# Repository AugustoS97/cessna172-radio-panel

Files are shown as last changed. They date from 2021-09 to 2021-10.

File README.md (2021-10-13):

# cessna-radio-panel

Radio panel for COM or NAV for a Cessna 172 to use with MSFS2020, XPlane and Prepar3D using the software MobiFlight.

# Repo contents

## Cessna-radio-stack-pcb
This folder contents the PCB design for the radio module. The design is the same for COM and NAV, it only changes on the frame. This PCB needs to be connected to the Arduino Mega using the Mega-pro-mini module designed in this repository. There is a GERBER folder to send the design to JLCPCB (www.jlcpcb.com) or you can ask me to buy it finished (augustosamuelhdezmartin@gmail.com).

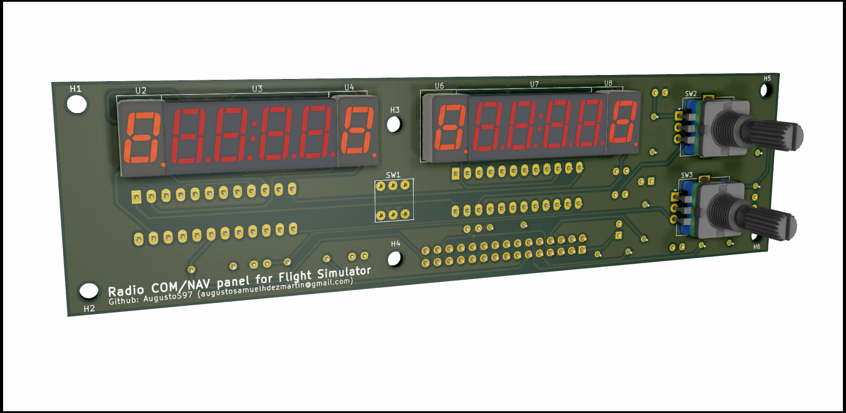
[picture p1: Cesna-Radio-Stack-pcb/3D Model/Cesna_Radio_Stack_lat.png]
Render PCB radio

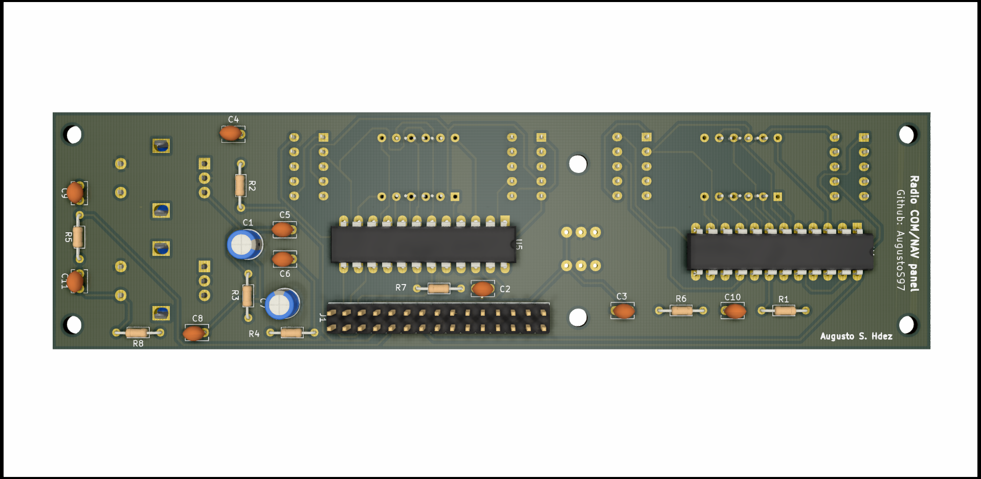
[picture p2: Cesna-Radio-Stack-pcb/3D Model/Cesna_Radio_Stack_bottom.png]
Render PCB bottom


To make this PCB you need this components (you can find the list in cessna172-radio-panel/Cesna-Radio-Stack-pcb/Docs/Cesna_Radio_Stack.csv):
- 4x Display 7 segments 0.36" 1 bit Common Cathode red (https://www.aliexpress.com/item/1005001852229452.html?spm=a2g0o.cart.0.0.44e13c00yVY6Ir&mp=1)
- 2x Display 7 segments 0.36" 4 bit Common Cathode red AS3161 (https://www.aliexpress.com/item/32673704841.html?spm=a2g0o.cart.0.0.44e13c00yVY6Ir&mp=1).
- 2x Rottary Encoder EC11 (https://es.aliexpress.com/item/1005002931777351.html?spm=a2g0o.cart.0.0.44e13c00yVY6Ir&mp=1) 
- 1x Button 8x8 (https://www.aliexpress.com/item/32467872702.html?spm=a2g0o.cart.0.0.44e13c00yVY6Ir&mp=1)
- 2x MAX7219 DIP24 (https://www.aliexpress.com/item/32874536319.html?spm=a2g0o.cart.0.0.44e13c00yVY6Ir&mp=1)
- 1x PinHeader 2x36 pins (https://www.aliexpress.com/item/33004522737.html?spm=a2g0o.cart.0.0.44e13c00yVY6Ir&mp=1)
- 8x 1k Resistor THT
- 7x 10nF Ceramic Capacitor THT
- 2x 150nF Ceramic Capacitor THT
- 2x 22uF Electrolitic Capcitor 16V

## Mega2560-pro-mini-radio
This folder contents the PCB design for the microcontroller. The design connects 2 NAV modules, 2 COM modules or 1 NAv and 1 COM modules. There is a GERBER folder to send the design to JLCPCB (www.jlcpcb.com) or you can ask me to buy it finished (augustosamuelhdezmartin@gmail.com).

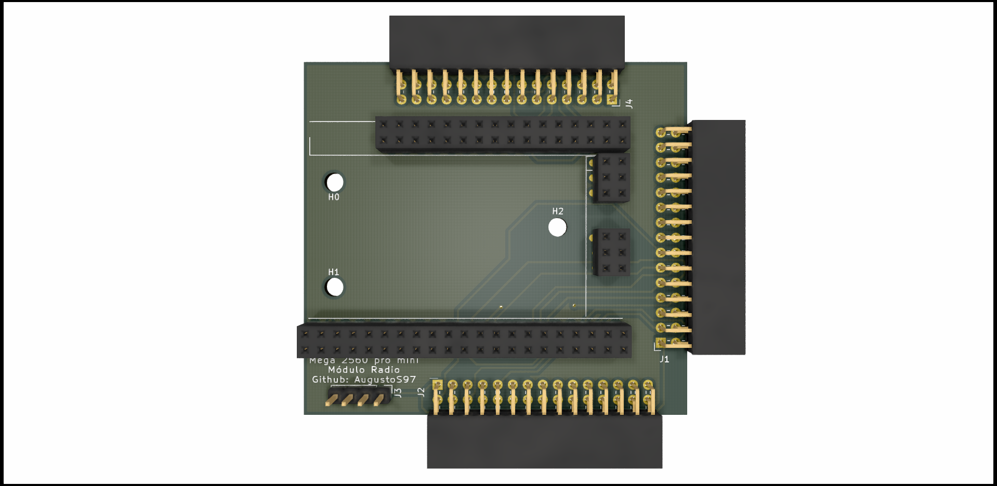
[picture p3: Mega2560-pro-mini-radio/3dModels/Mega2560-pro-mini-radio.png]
Render PCB radio


To make this PCB you need this components (you can find the list in cessna172-radio-panel/Mega2560-pro-mini-radio/docs/Mega2560-pro-mini-radio.csv):
- 1x Mega 2650 Pro mini (https://www.aliexpress.com/item/1005001798708448.html?spm=a2g0o.cart.0.0.44e13c00yVY6Ir&mp=1)
- 3x PinHeader male 2x36 pins 2.54 mm (https://www.aliexpress.com/item/32993182990.html?spm=a2g0o.cart.0.0.44e13c00yVY6Ir&mp=1)
- 3x PinHeader Female 1x40 pins 2.54mm (https://www.aliexpress.com/item/32993182990.html?spm=a2g0o.cart.0.0.44e13c00yVY6Ir&mp=1)
- 2x IDC 2x20 pins 2.54mm Cable (https://www.aliexpress.com/item/33029492417.html?spm=a2g0o.cart.0.0.44e13c00yVY6Ir&mp=1): One for each module

## Frame Design
This folders contents the FreeCAD design for the exterior panel. It is based on the c172-xpndr design (https://github.com/kkr0kk/c172-xpndr), so it must be use with this Transponder and AutoPilot modules.

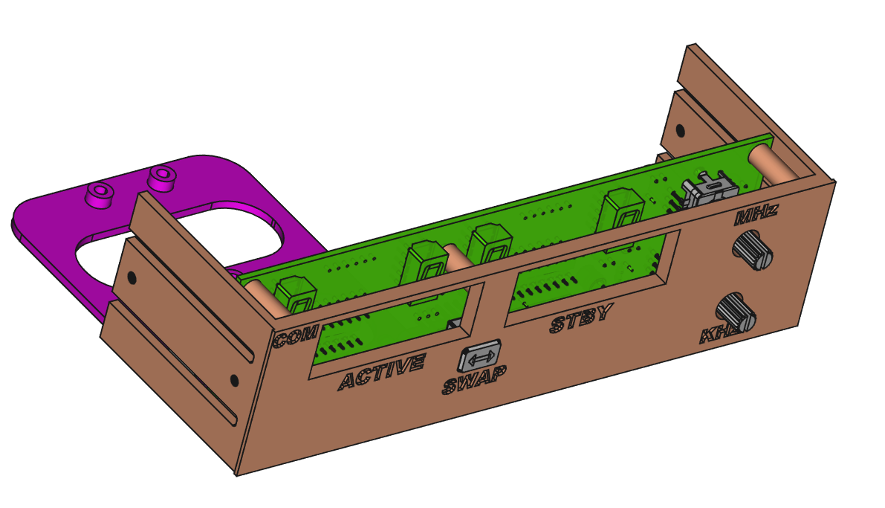
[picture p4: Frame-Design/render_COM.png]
FreeCAD design


Also the 3D model are available in STL folder, so you can print this panels with 2 colors or you can also contact me to buy a finished panel (augustosamuelhdezmartin@gmail.com).

## Assembly 
Finallly, the COM panel is assembly as shown in the next picture.

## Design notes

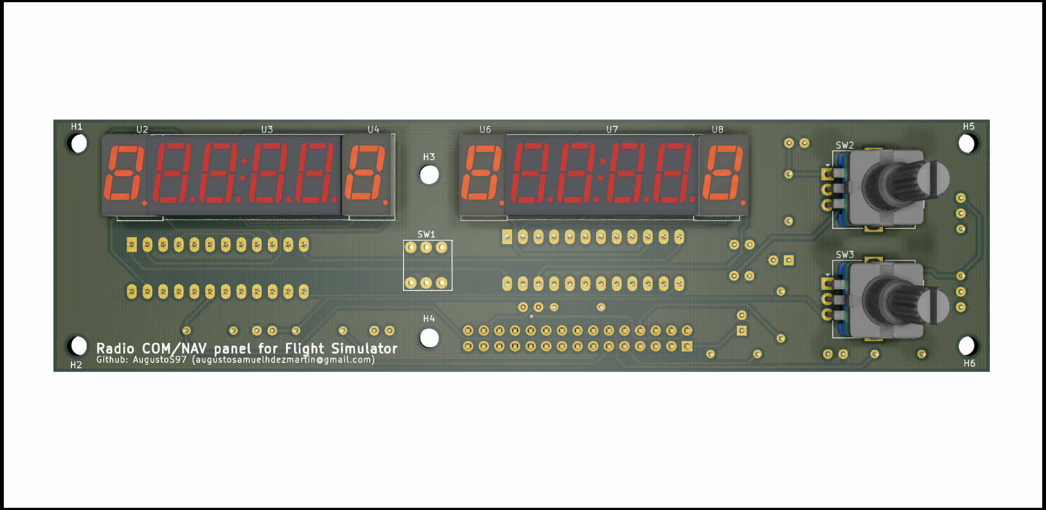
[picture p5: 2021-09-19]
Cesna-Radio-Stack-pcb/3D Model/Cesna_Radio_Stack.png

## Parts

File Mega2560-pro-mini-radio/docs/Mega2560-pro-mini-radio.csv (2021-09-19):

Ref | Qnty | Value | Cmp name | Footprint | Description | Vendor
J1, | 1 | COM_CONN | Conn_02x15_Odd_Even | Connector_PinSocket_2.54mm:PinSocket_2x15_P2.54mm_Horizontal | Generic connector, double row, 02x15, odd/even pin numbering scheme (row 1 odd numbers, row 2 even numbers), script generated (kicad-library-utils/schlib/autogen/connector/)
J2, | 1 | NAV_CONN | Conn_02x15_Odd_Even | Connector_PinSocket_2.54mm:PinSocket_2x15_P2.54mm_Horizontal | Generic connector, double row, 02x15, odd/even pin numbering scheme (row 1 odd numbers, row 2 even numbers), script generated (kicad-library-utils/schlib/autogen/connector/)
J3, | 1 | Power_Conn | Conn_01x04 | Connector_PinHeader_2.54mm:PinHeader_1x04_P2.54mm_Vertical | Generic connector, single row, 01x04, script generated (kicad-library-utils/schlib/autogen/connector/)
MCU1, | 1 | Mega_Embebido | Master_Arduino_Mega_Embebido_Arduino_Mega_v3 | Mega2560-pro-mini-radio:MEGA_Embebido

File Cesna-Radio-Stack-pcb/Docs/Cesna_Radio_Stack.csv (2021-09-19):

Ref | Qnty | Value | Cmp name | Footprint | Description | Vendor
C1, C7, | 2 | 22uF | CP_Small | Capacitor_THT:CP_Radial_D5.0mm_P2.50mm | Polarized capacitor, small symbol
C2, C8, | 2 | 150nF | C_Small | Capacitor_THT:C_Disc_D3.8mm_W2.6mm_P2.50mm | Unpolarized capacitor, small symbol
C3, C4, C5, C6, C9, C10, C11, | 7 | 10nF | C_Small | Capacitor_THT:C_Disc_D3.8mm_W2.6mm_P2.50mm | Unpolarized capacitor, small symbol
J1, | 1 | Conn_02x15_Odd_Even | Conn_02x15_Odd_Even | Connector_PinHeader_2.54mm:PinHeader_2x15_P2.54mm_Vertical | Generic connector, double row, 02x15, odd/even pin numbering scheme (row 1 odd numbers, row 2 even numbers), script generated (kicad-library-utils/schlib/autogen/connector/)
R1, R2, R3, R4, R5, R6, R7, R8, | 8 | 10k | R_Small | Resistor_THT:R_Axial_DIN0204_L3.6mm_D1.6mm_P7.62mm_Horizontal | Resistor, small symbol
SW1, | 1 | SW_COM-DPDT 8x8 mm | SW_Push_DPDT | Button_Switch_THT:SW_DIP_SPSTx03_Slide_9.78x9.8mm_W7.62mm_P2.54mm | Momentary Switch, dual pole double throw
SW2, | 1 | NAV_ENC-EC11 | Rotary_Encoder_Switch | Rotary_Encoder:RotaryEncoder_Alps_EC12E-Switch_Vertical_H20mm | Rotary encoder, dual channel, incremental quadrate outputs, with switch
SW3, | 1 | COM_ENC-EC11 | Rotary_Encoder_Switch | Rotary_Encoder:RotaryEncoder_Alps_EC12E-Switch_Vertical_H20mm | Rotary encoder, dual channel, incremental quadrate outputs, with switch
U1, U5, | 2 | MAX7219 | MAX7219 | Package_DIP:DIP-24_W7.62mm_LongPads | 8-Digit LED Display Driver
U2, | 1 | LD-3161-AS NAV/COM_ACTV | HDSP-A153 | Cesna_Radio_Stack:3161AS_7_Segmentos | One digit 7 segment red, common cathode
U3, | 1 | 3641-AS NAV/COM_ACTV | CC56-12EWA | Cesna_Radio_Stack:3641-AS | 4 digit 7 segment high efficiency red LED, common cathode
U4, | 1 | LD-3161-AS NAV/COM_ACTV_KHZ | HDSP-A153 | Cesna_Radio_Stack:3161AS_7_Segmentos | One digit 7 segment red, common cathode
U6, | 1 | LD-3161-AS NAV/COM_STB | HDSP-A153 | Cesna_Radio_Stack:3161AS_7_Segmentos | One digit 7 segment red, common cathode
U7, | 1 | 3641-AS NAV/COM_STB | CC56-12EWA | Cesna_Radio_Stack:3641-AS | 4 digit 7 segment high efficiency red LED, common cathode
U8, | 1 | LD-3161-AS NAV/COM_STB_KHZ | HDSP-A153 | Cesna_Radio_Stack:3161AS_7_Segmentos | One digit 7 segment red, common cathode

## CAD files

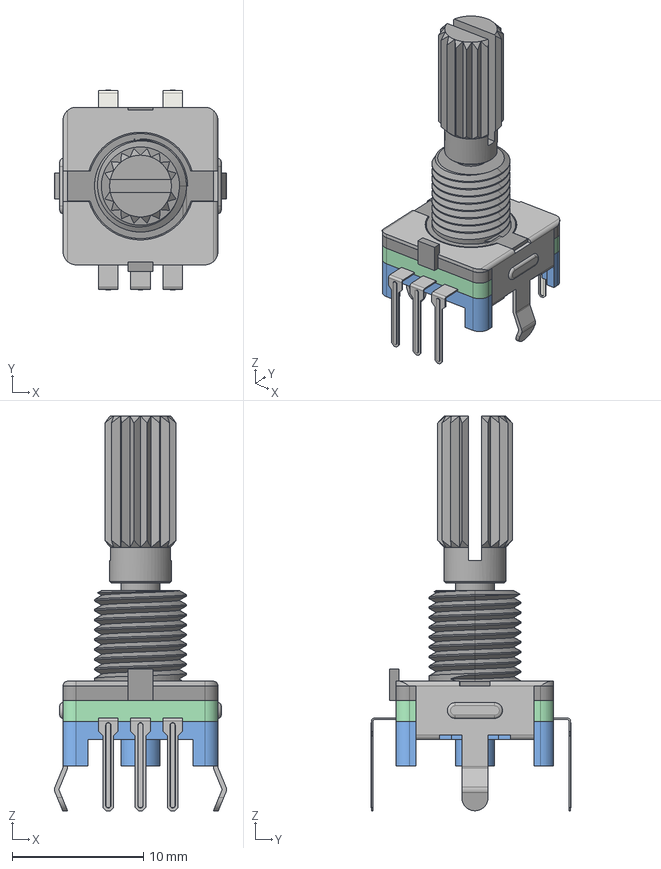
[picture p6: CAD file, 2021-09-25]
Frame-Design/EC11_Rotary_Encoder_Switched.step
13.1 x 15.3 x 30.1 mm

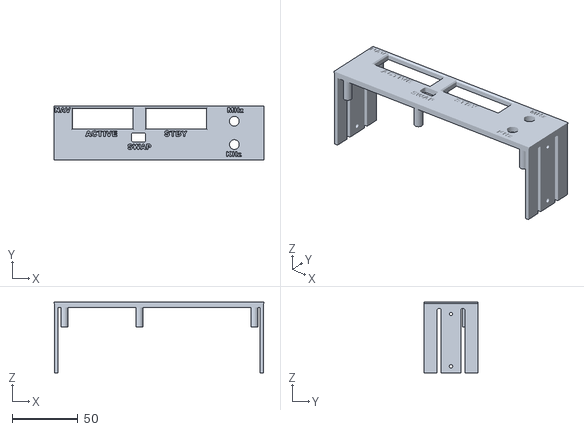
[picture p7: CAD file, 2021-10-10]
STL/Frame-NAV.stl
160.0 x 41.0 x 54.0

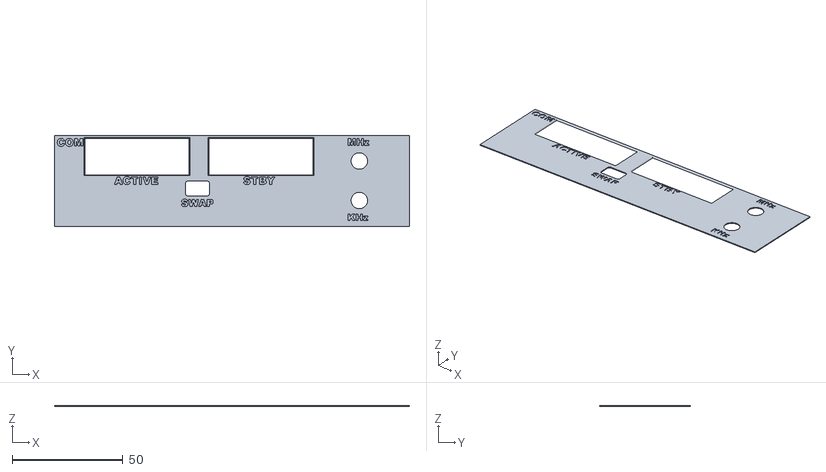
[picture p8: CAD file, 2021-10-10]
STL/Frame-COM-front.stl
160.0 x 41.0 x 0.4

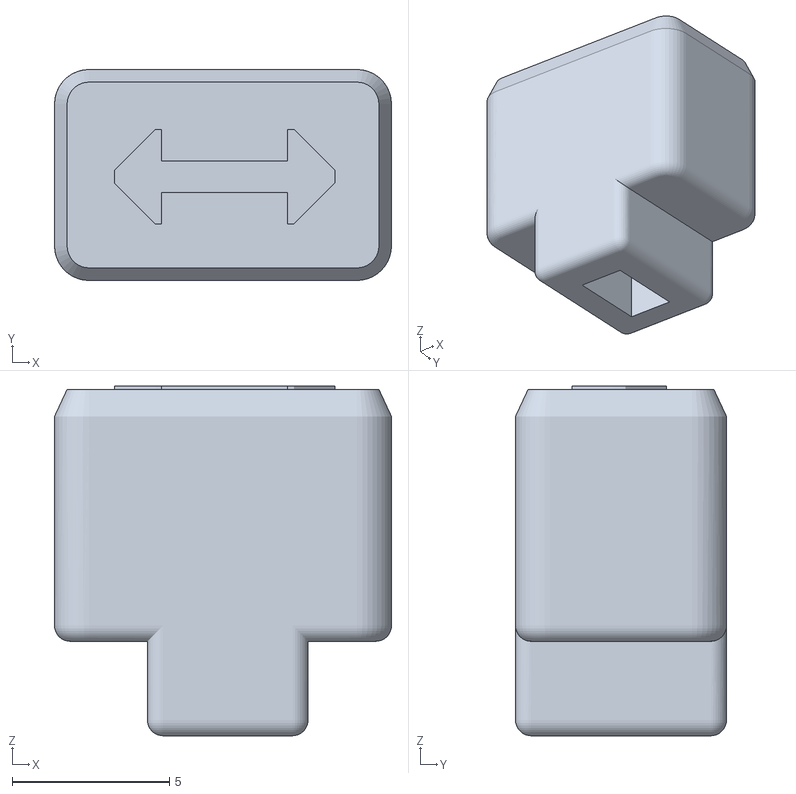
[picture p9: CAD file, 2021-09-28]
STL/Swap-Button.stl
10.7 x 6.70 x 11.1

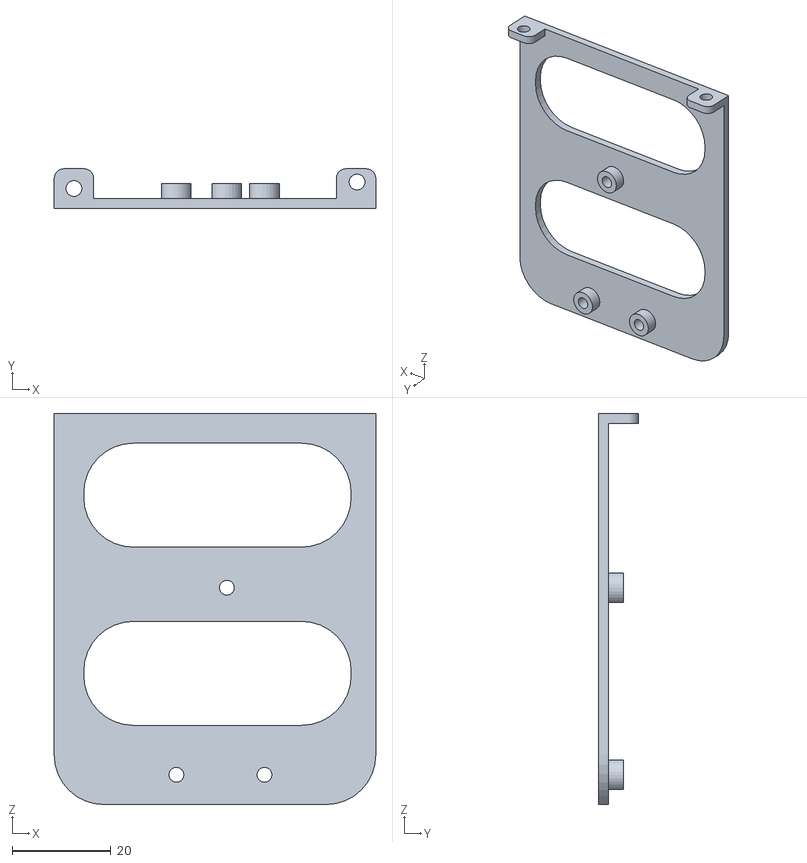
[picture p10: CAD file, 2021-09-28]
STL/Soporte-ATMega.stl
65.0 x 8.00 x 79.0

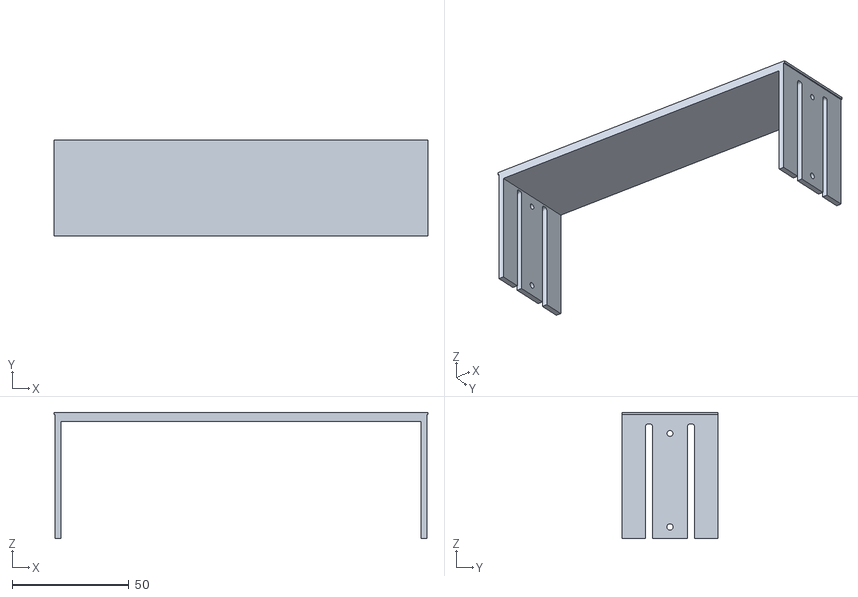
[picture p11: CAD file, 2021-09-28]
STL/Marco-vacio.stl
160.0 x 41.0 x 54.0

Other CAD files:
Frame-Design/chassis_without_text.STL
STL/Frame-COM.stl
STL/Button.stl

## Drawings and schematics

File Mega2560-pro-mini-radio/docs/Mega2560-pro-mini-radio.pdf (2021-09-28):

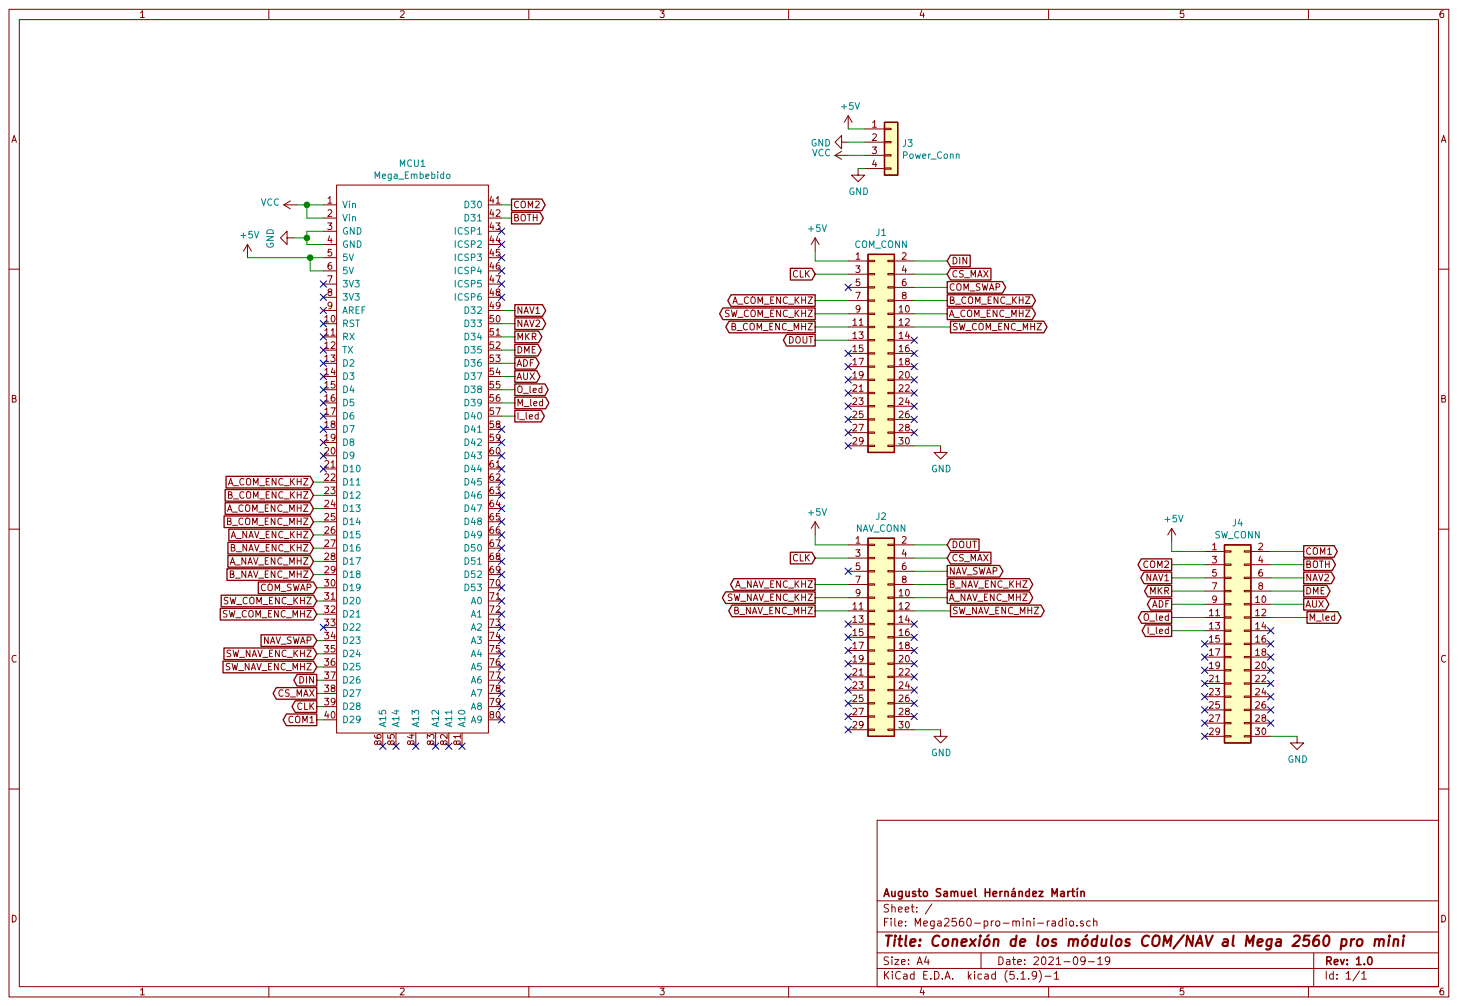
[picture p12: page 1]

File: Mega2560-pro-mini-radio.sch Sheet: / Augusto Samuel Hernández Martín GND

Id: 1/1 Title: Conexión de los módulos COM/NAV al Mega 2560 pro mini

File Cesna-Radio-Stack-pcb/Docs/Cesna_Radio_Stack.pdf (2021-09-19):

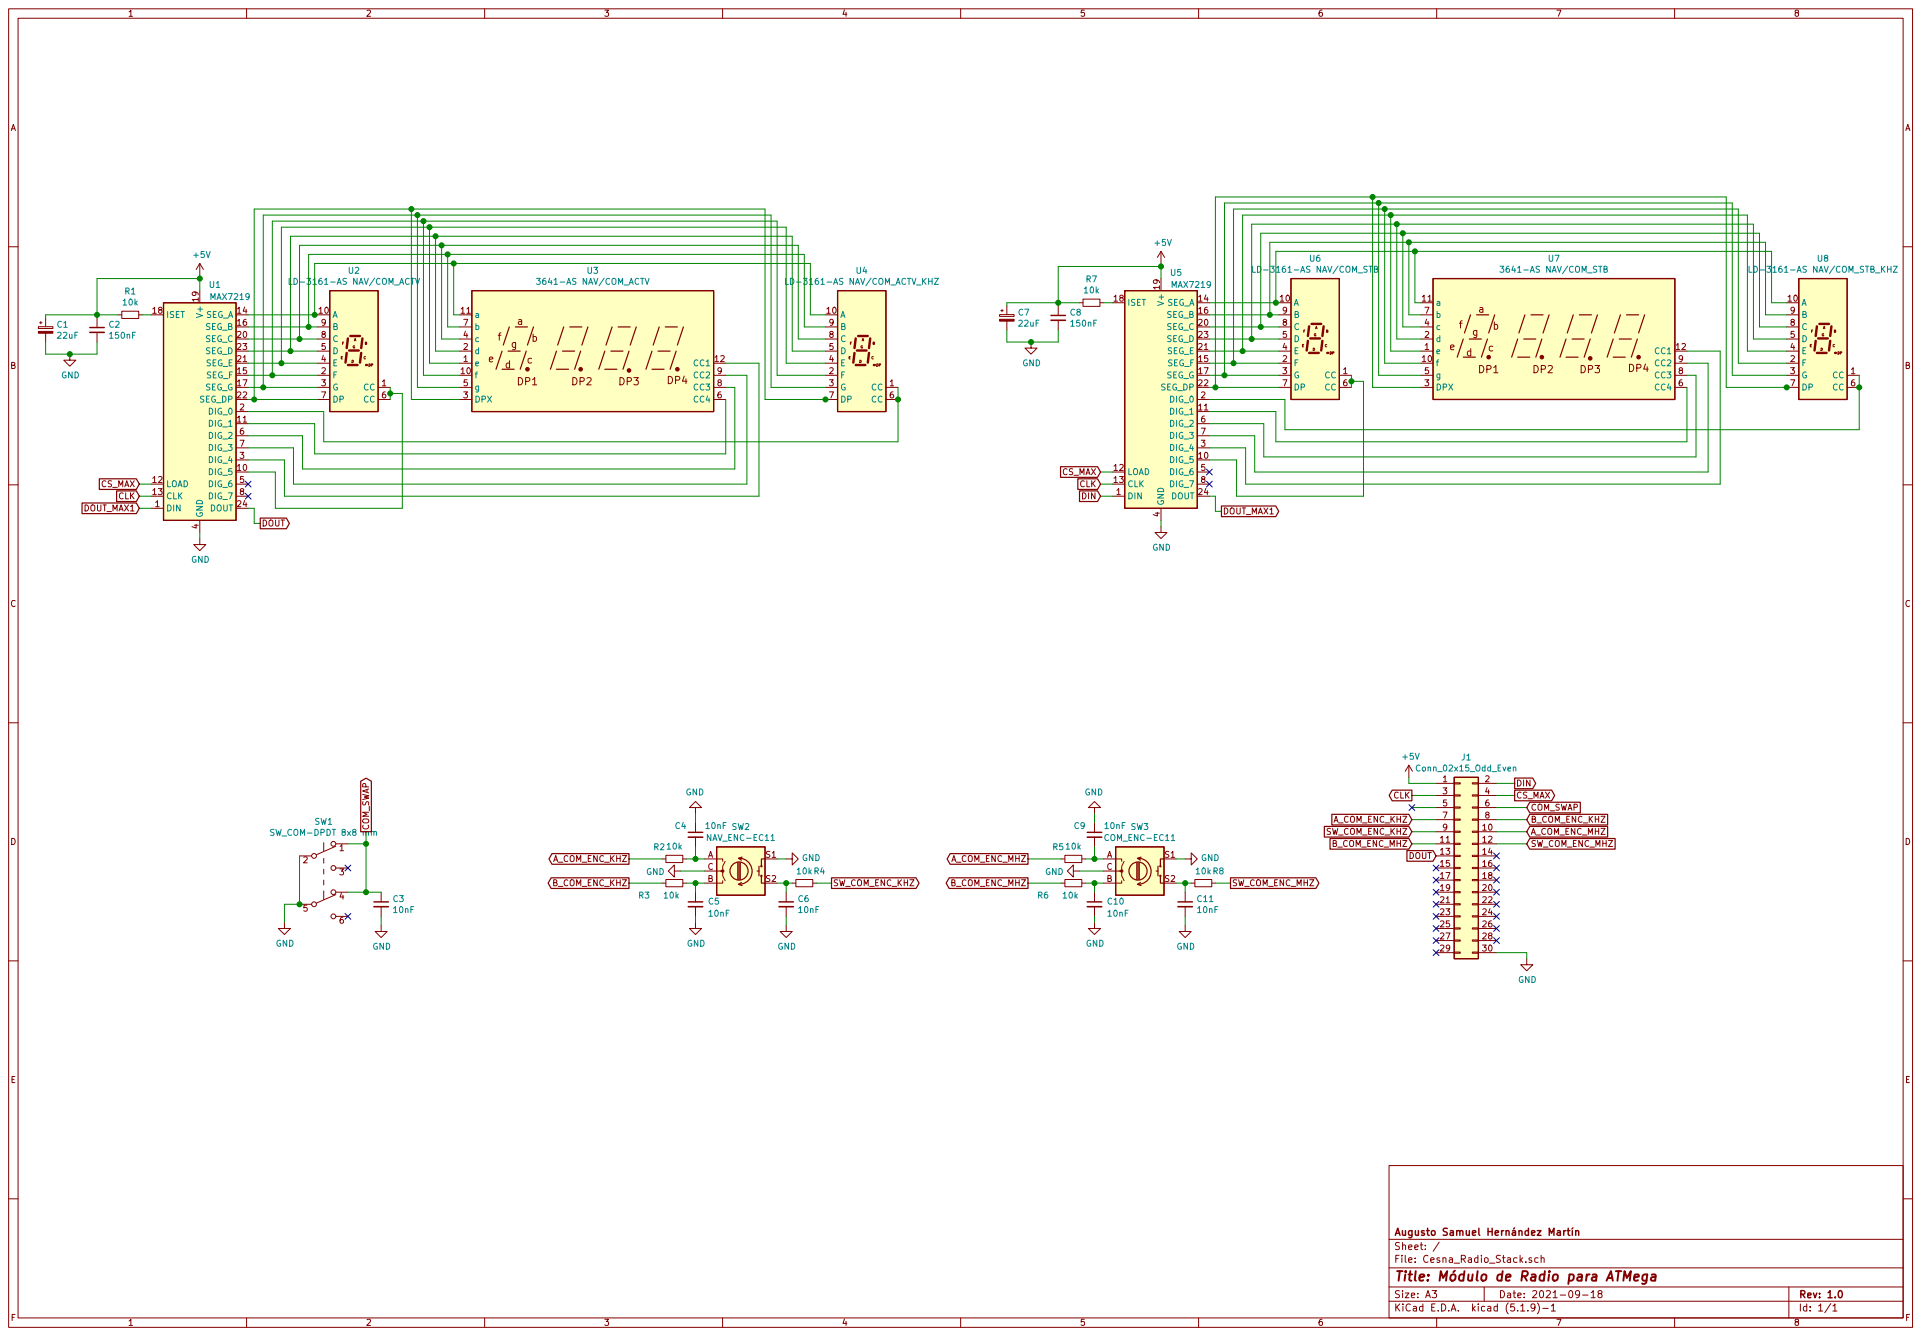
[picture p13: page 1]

3641-AS NAV/COM_STB GND GND

LD-3161-AS NAV/COM_STB_KHZ GND GND

File: Cesna_Radio_Stack.sch Sheet: / Augusto Samuel Hernández Martín R5 10k GND

Id: 1/1 Title: Módulo de Radio para ATMega

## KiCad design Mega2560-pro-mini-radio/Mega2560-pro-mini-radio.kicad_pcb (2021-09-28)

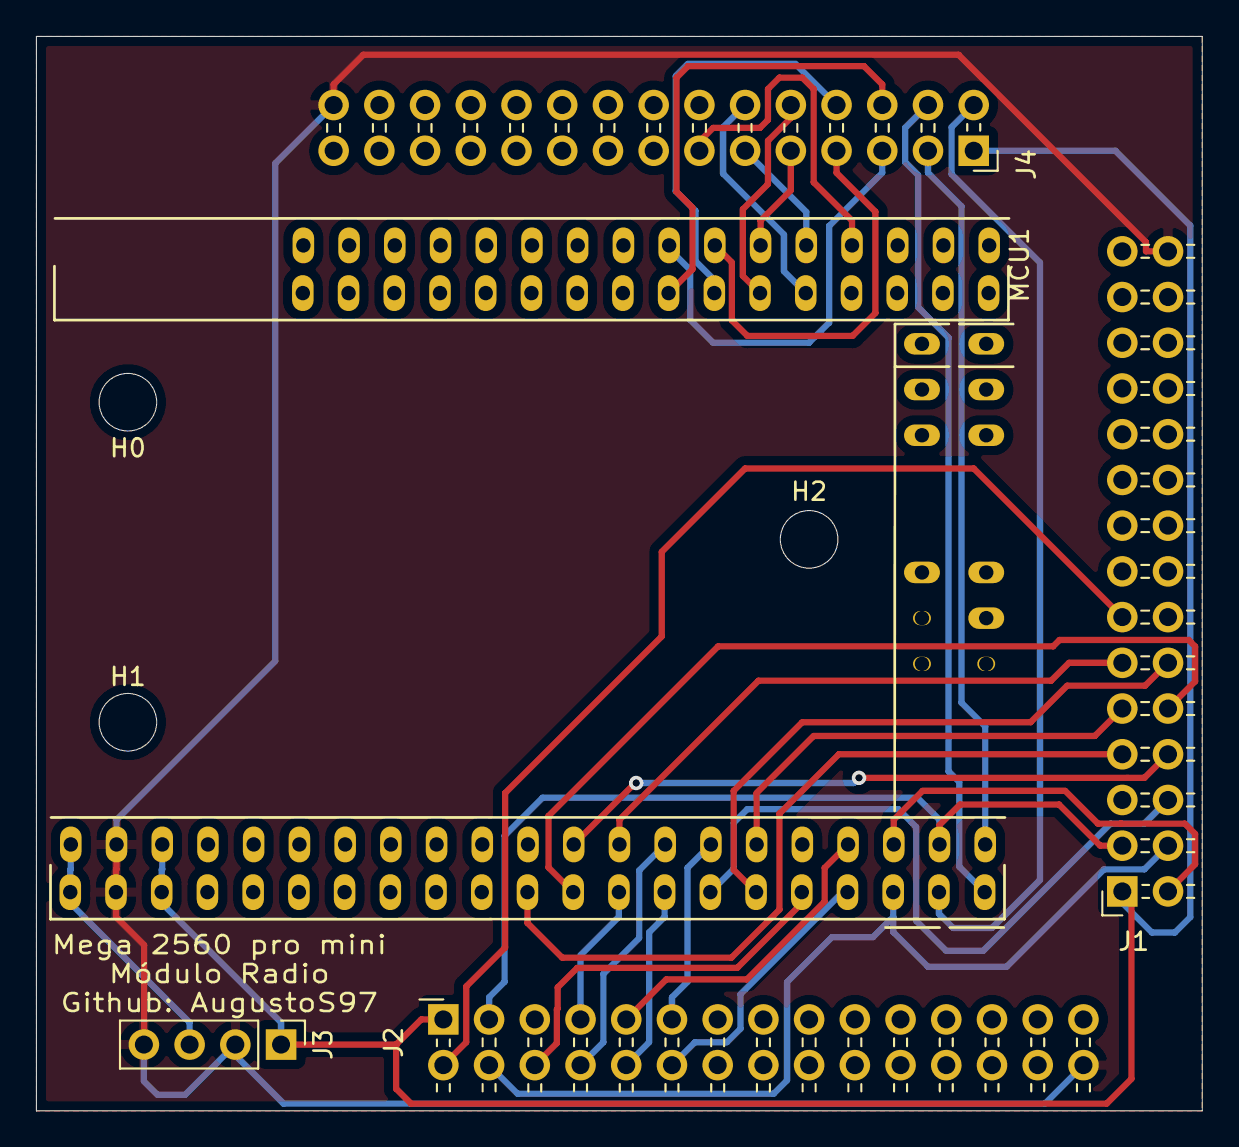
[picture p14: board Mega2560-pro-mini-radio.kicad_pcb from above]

Board: 2 copper layers, 64.8 x 59.7 mm, 8 parts (0 on the bottom side), 33 nets.

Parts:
H0, H1, H2: MountingHole_3.2mm_M3
J1: COM_CONN; PinSocket_2x15_P2.54mm_Horizontal
J2: NAV_CONN; PinSocket_2x15_P2.54mm_Horizontal
J3: Power_Conn; PinHeader_1x04_P2.54mm_Vertical
J4: SW_CONN; PinSocket_2x15_P2.54mm_Horizontal
MCU1: Mega_Embebido; MEGA_Embebido

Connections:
+5V: J1.1, J2.1, J3.1, J4.1, MCU1.5, MCU1.6
ADF: J4.9, MCU1.53
AUX: J4.10, MCU1.54
A_COM_ENC_KHZ: J1.7, MCU1.22
A_COM_ENC_MHZ: J1.10, MCU1.24
A_NAV_ENC_KHZ: J2.7, MCU1.26
A_NAV_ENC_MHZ: J2.10, MCU1.28
BOTH: J4.4, MCU1.42
B_COM_ENC_KHZ: J1.8, MCU1.23
B_COM_ENC_MHZ: J1.11, MCU1.25
B_NAV_ENC_KHZ: J2.8, MCU1.27
B_NAV_ENC_MHZ: J2.11, MCU1.29
CLK: J1.3, J2.3, MCU1.39
COM1: J4.2, MCU1.40
COM2: J4.3, MCU1.41
COM_SWAP: J1.6, MCU1.30
CS_MAX: J1.4, J2.4, MCU1.38
DIN: J1.2, MCU1.37
DME: J4.8, MCU1.52
DOUT: J1.13, J2.2
GND: J1.30, J2.30, J3.2, J3.4, J4.30, MCU1.3, MCU1.4
I_led: J4.13, MCU1.57
MKR: J4.7, MCU1.51
M_led: J4.12, MCU1.56
NAV1: J4.5, MCU1.49
NAV2: J4.6, MCU1.50
NAV_SWAP: J2.6, MCU1.34
O_led: J4.11, MCU1.55
SW_COM_ENC_KHZ: J1.9, MCU1.31
SW_COM_ENC_MHZ: J1.12, MCU1.32
SW_NAV_ENC_KHZ: J2.9, MCU1.35
SW_NAV_ENC_MHZ: J2.12, MCU1.36
VCC: J3.3, MCU1.1, MCU1.2

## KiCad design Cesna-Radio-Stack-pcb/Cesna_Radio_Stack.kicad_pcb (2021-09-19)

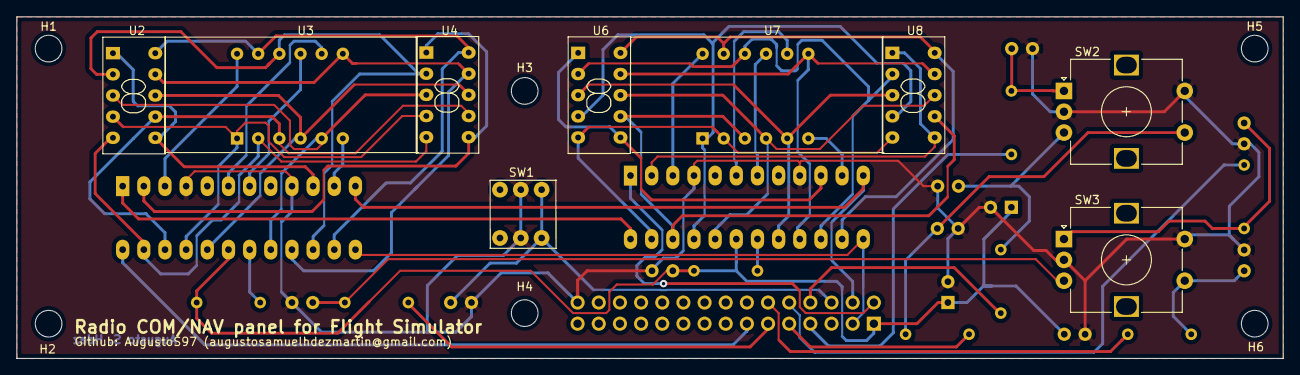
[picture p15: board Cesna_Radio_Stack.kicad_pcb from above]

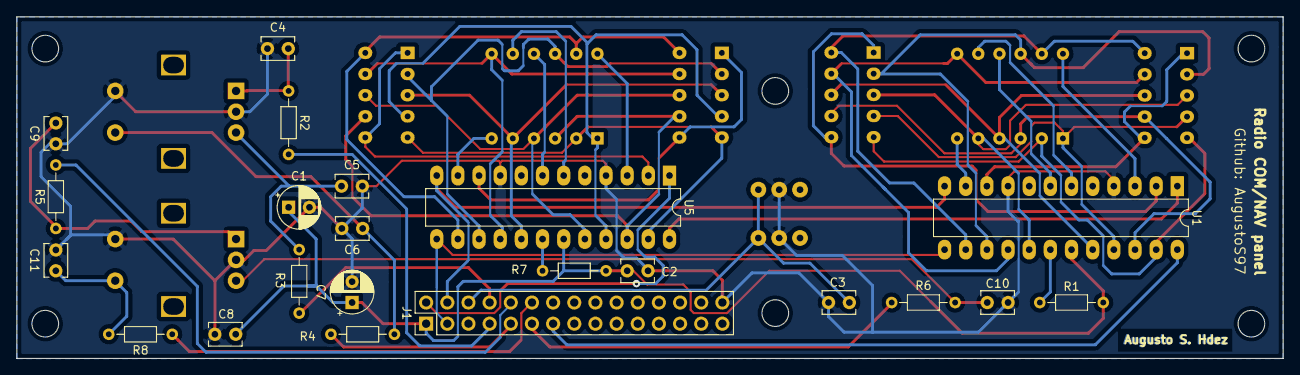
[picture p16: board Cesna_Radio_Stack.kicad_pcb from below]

Board: 2 copper layers, 152.0 x 41.0 mm, 37 parts (22 on the bottom side), 50 nets.

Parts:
C1, C7: 22uF; CP_Radial_D5.0mm_P2.50mm
C2, C8: 150nF; C_Disc_D3.8mm_W2.6mm_P2.50mm
C3, C4, C5, C6, C9, C10, C11: 10nF; C_Disc_D3.8mm_W2.6mm_P2.50mm
H1, H2, H3, H4, H5, H6: MountingHole_3.2mm_M3
J1: Conn_02x15_Odd_Even; PinHeader_2x15_P2.54mm_Vertical
R1, R2, R3, R4, R5, R6, R7, R8: 10k; R_Axial_DIN0204_L3.6mm_D1.6mm_P7.62mm_Horizontal
SW1: SW_COM; SPDT_8x8
SW2: NAV_ENC; RotaryEncoder_Alps_EC12E-Switch_Vertical_H20mm
SW3: COM_ENC; RotaryEncoder_Alps_EC12E-Switch_Vertical_H20mm
U1, U5: MAX7219; DIP-24_W7.62mm_LongPads
U2: HDSP-A153 NAV/COM_ACTV; 3161AS_7_Segmentos
U3: 3641-AS NAV/COM_ACTV; 3641-AS
U4: HDSP-A153 NAV/COM_ACTV_KHZ; 3161AS_7_Segmentos
U6: HDSP-A153 NAV/COM_STB; 3161AS_7_Segmentos
U7: 3641-AS NAV/COM_STB; 3641-AS
U8: HDSP-A153 NAV/COM_STB_KHZ; 3161AS_7_Segmentos

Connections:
+5V: C1.1, C2.1, C7.1, C8.1, J1.1, R1.2, R7.2, U1.19, U5.19
A_COM_ENC_KHZ: J1.7, R2.2
A_COM_ENC_MHZ: J1.10, R5.2
B_COM_ENC_KHZ: J1.8, R3.2
B_COM_ENC_MHZ: J1.11, R6.2
CLK: J1.3, U1.13, U5.13
COM_SWAP: C3.1, J1.6, SW1.1, SW1.4
CS_MAX: J1.4, U1.12, U5.12
DIN: J1.2, U5.1
DOUT: J1.13, U1.24
DOUT_MAX1: U1.1, U5.24
GND: C1.2, C2.2, C3.2, C4.1, C5.2, C6.2, C7.2, C8.2, C9.1, C10.2, C11.2, J1.30, SW1.2, SW1.5, SW2.C, SW2.S1, SW3.C, SW3.S1, U1.4, U1.9, U5.4, U5.9
unnamed: C4.2, R2.1, SW2.A
unnamed: C5.1, R3.1, SW2.B
unnamed: C6.1, R4.2, SW2.S2
unnamed: C9.2, R5.1, SW3.A
unnamed: C10.1, R6.1, SW3.B
unnamed: C11.1, R8.2, SW3.S2
unnamed: R1.1, U1.18
unnamed: R7.1, U5.18
unnamed: U1.2, U4.1, U4.6
unnamed: U1.3, U3.12
unnamed: U1.6, U3.8
unnamed: U1.7, U3.9
unnamed: U1.10, U2.1, U2.6
unnamed: U1.11, U3.6
unnamed: U1.14, U2.10, U3.11, U4.10
unnamed: U1.15, U2.2, U3.10, U4.2
unnamed: U1.16, U2.9, U3.7, U4.9
unnamed: U1.17, U2.3, U3.5, U4.3
unnamed: U1.20, U2.8, U3.4, U4.8
unnamed: U1.21, U2.4, U3.1, U4.4
unnamed: U1.22, U2.7, U3.3, U4.7
unnamed: U1.23, U2.5, U3.2, U4.5
unnamed: U5.2, U8.1, U8.6
unnamed: U5.3, U7.12
unnamed: U5.6, U7.8
unnamed: U5.7, U7.9
unnamed: U5.10, U6.1, U6.6
unnamed: U5.11, U7.6
unnamed: U5.14, U6.10, U7.11, U8.10
unnamed: U5.15, U6.2, U7.10, U8.2
unnamed: U5.16, U6.9, U7.7, U8.9
unnamed: U5.17, U6.3, U7.5, U8.3
unnamed: U5.20, U6.8, U7.4, U8.8
unnamed: U5.21, U6.4, U7.1, U8.4
unnamed: U5.22, U6.7, U7.3, U8.7
unnamed: U5.23, U6.5, U7.2, U8.5
SW_COM_ENC_KHZ: J1.9, R4.1
SW_COM_ENC_MHZ: J1.12, R8.1

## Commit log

2021-09-19 PCB Radio panel add.
    [Cesna_Radio_Stack.csv, Cesna_Radio_Stack.kicad_pcb, Cesna_Radio_Stack.sch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]
2021-09-19 Mega2560 pcb add.
    [Cesna_Radio_Stack-B_Cu.gbr, Cesna_Radio_Stack-B_Mask.gbr, Cesna_Radio_Stack-B_Paste.gbr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]
2021-09-25 En proceso de diseño del marco frontal impreso.
    [EC11_Rotary_Encoder_Switched.step, chassis_without_text.STL]
2021-09-28 PCB de ATMega modificada para permitir conectar los switches de control de los modulos COM.
    [Mega2560-pro-mini-radio-B_Cu.gbr, Mega2560-pro-mini-radio-B_Mask.gbr, Mega2560-pro-mini-radio-B_Paste.gbr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]
2021-09-28 Añadidos los soportes para ATMega.
    [Button.stl, Frame-COM.stl, Frame-NAV.stl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]
2021-10-10 Modificados los Frames de COM y NAV
    [Frame-COM-front.stl, Frame-COM.stl, Frame-NAV.stl]
2021-10-10 Modificados los STL de los marcos NAV y COM
    [Frame-COM.stl, Frame-NAV.stl]
